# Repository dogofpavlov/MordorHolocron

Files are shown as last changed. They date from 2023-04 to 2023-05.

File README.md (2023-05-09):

# Sauron Holocron
This is a Lord of the Rings themed Holocron created by Ryan The Cyber Hobbit.

What is a Holocron?  A Holocron is a Star Wars ancient repository of knowledge and wisdom that can only be accessed by those skilled in the Force. In Star Wars, Jedi use them to record and preserve their teachings, creating a record for future generations seeking to understand the mysteries of the Force.

This is a "What if" scenario where we imagine Sauron in the Star Wars universe as a Sith Lord that created a Holocron.

This project was created with the help of this Thingiverse model, I used the "blank" option included: https://www.thingiverse.com/thing:3565057 

### 3D Printing Directions
I printed the models with a resin printer (Saturn 2) and few parts with my Creality Ender 3 Pro

### Build Video

* [Watch on my youtube channel](https://www.youtube.com/watch?v=eRCXtB5M6yg)

### Things I Used
* A Resin or FDM 3D Printer. I used a Saturn 2 (resin).
* Elegoo 405nm Standard Resin Grey 1000g
* Elegoo 405nm Standard Resin Clear Red 500g
* [Arduino Nano](https://www.amazon.com/dp/B07G99NNXL)
* [WS2812B LED Strip 60Pixels/M - 16.4 FT](https://www.amazon.com/dp/B01CDTEJBG)
* [1000mAh Lipo Rechargeable Battery with JST Connector](https://www.amazon.com/dp/B07BTV3W87)
* [SparkFun LiPo Charger/Booster - 5V/1A](https://www.amazon.com/dp/B076953CYL)
* [4 Inch Micro Male to Female USB Extension Cable](https://www.amazon.com/dp/B071NR19BQ)
* [Momentary Tactile Push Button Switch - 12mm x 12mm x 4.3mm](https://www.amazon.com/dp/B07CG6HVY9)
* [Slide Toggle Switches 3 Pin 2 Position - 12.7mm x 6.6mm x 13.2mm (l*w*h)](https://www.amazon.com/dp/B08H5BQ6Y8)
* [1000uf 25V Capacitor](https://www.amazon.com/dp/B06WGPNM19)
* [Micro SD Card 8GB Max](https://www.amazon.com/dp/B085ZVG84C)
* [1K Resistor](https://www.amazon.com/dp/B06WRQS97C)
* [330 ohm Resistor](https://www.amazon.com/dp/B06WRQS97C)
* [Mini MP3 Player - DFPlayer](https://www.amazon.com/dp/B07Y2YKYRS)
* [3 Watt 8 Ohm Speaker](https://www.amazon.com/dp/B07FTB281F)
* Use a breadboard to test everything before you Solder
* Plenty of Solder (70+ connections)
* [Krylon Flat Black Spray Paint](https://www.amazon.com/Krylon-K05546007-COLORmaxx-Spray-Aerosol/dp/B07LFWTW93) 
* [Krylon Flat Clear Coat](https://www.amazon.com/Krylon-K05547007-COLORmaxx-Spray-Aerosol/dp/B07LFWTQNG)
* [Dupli-Color Metal Cast Red](https://www.amazon.com/dp/B000994BUM)
* [Rub 'n Buff - Antique Gold](https://www.amazon.com/dp/B0BC224DPV)
* Sand Paper (320, 600, 1000) grit
* Hot Glue
* Gorilla Super Glue Gel
* [J-B Weld Plastic Bonder](https://www.amazon.com/dp/B01IBOK7FE)

### Arduino Prerequisites
* Some experience with [Arduino](https://www.arduino.cc/)
* Be sure to have the Arduino Nano board installed in your environment.
* Install the [Bounce2](https://github.com/thomasfredericks/Bounce2) library.
* Install the [ButtonEvents](https://github.com/fasteddy516/ButtonEvents) library.
* Install the [DFPlayer Mini Fast](https://github.com/PowerBroker2/DFPlayerMini_Fast) library
If you alter the number of LEDs you use, be sure to change the code "NUM_LEDS" to reflect this.

### Wiring Diagram
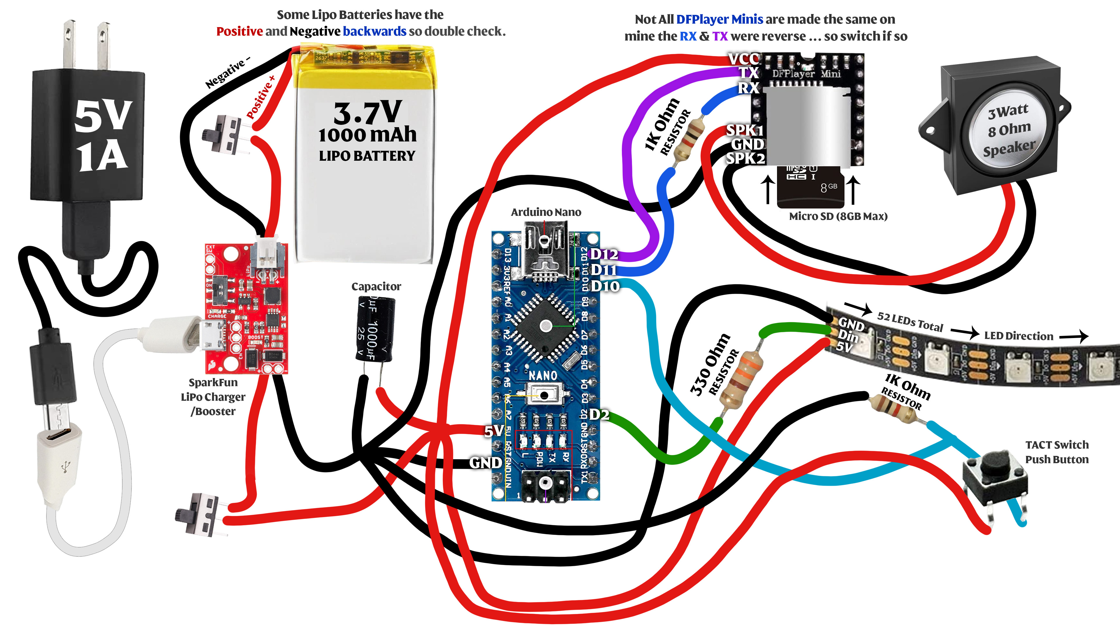
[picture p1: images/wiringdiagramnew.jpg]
Wiring diagram


### Author
Ryan "The Cyber Hobbit"

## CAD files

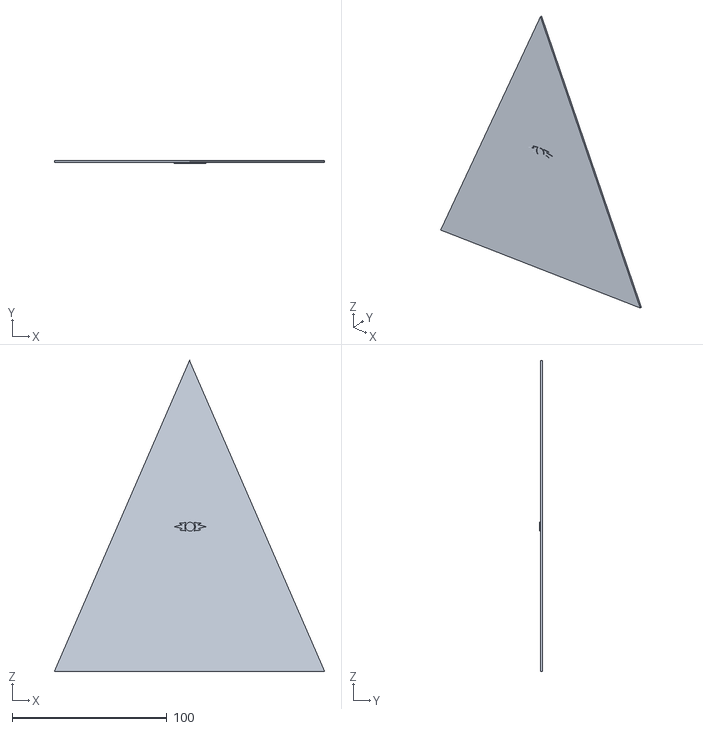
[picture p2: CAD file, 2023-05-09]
InnerPanel.stl
175.0 x 1.75 x 201.2

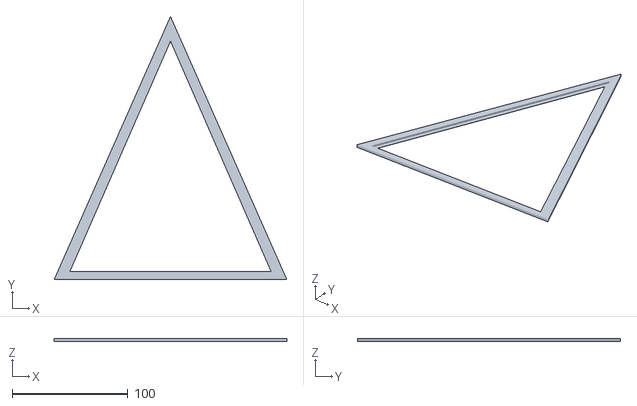
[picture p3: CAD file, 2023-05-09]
InsideFrame.stl
201.2 x 227.5 x 2.45

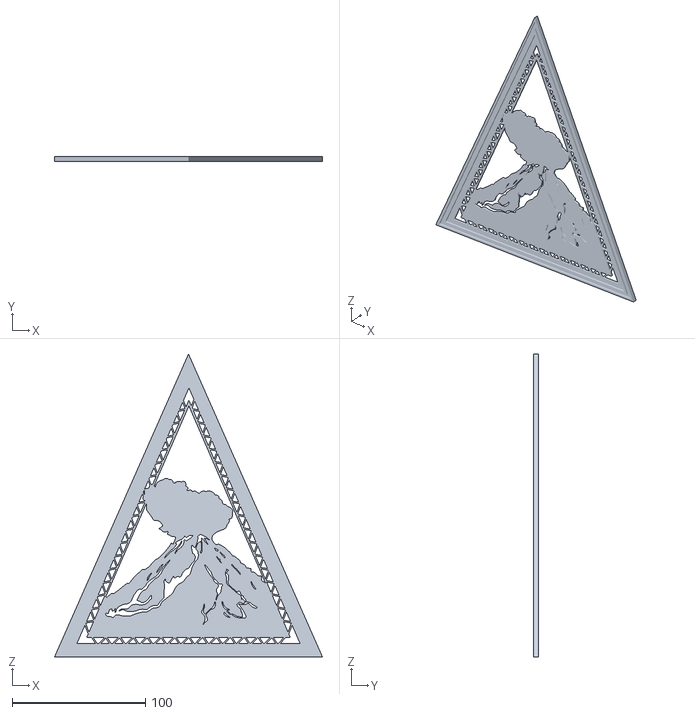
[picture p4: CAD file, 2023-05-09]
Side Mount Doom.stl
201.2 x 3.50 x 227.5

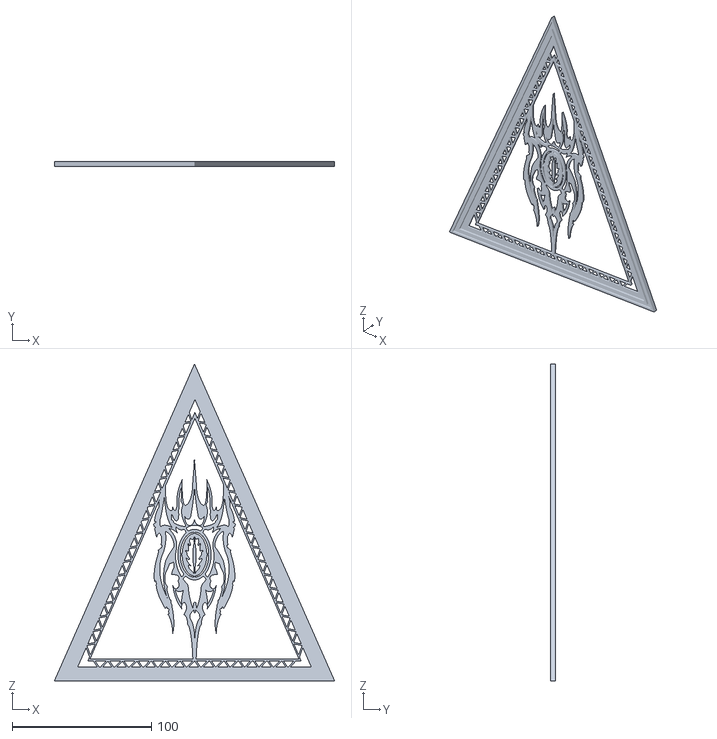
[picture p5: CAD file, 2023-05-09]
Side Eye.stl
201.2 x 3.50 x 227.5

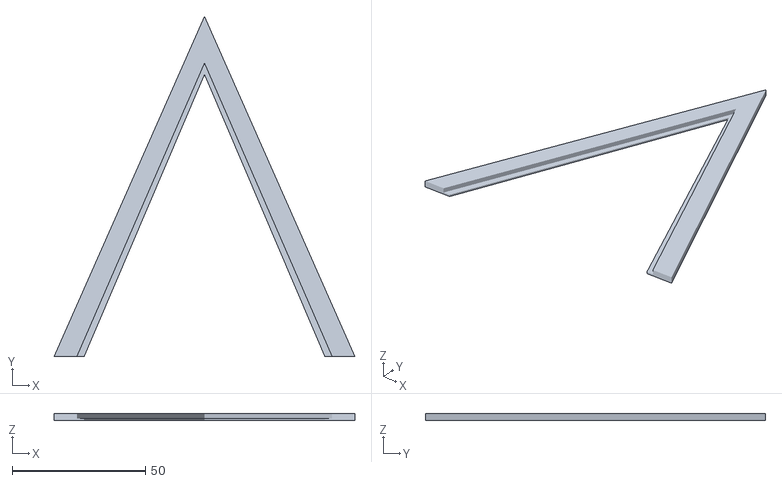
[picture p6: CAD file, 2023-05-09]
InsideFramePart1.stl
112.8 x 127.5 x 2.45

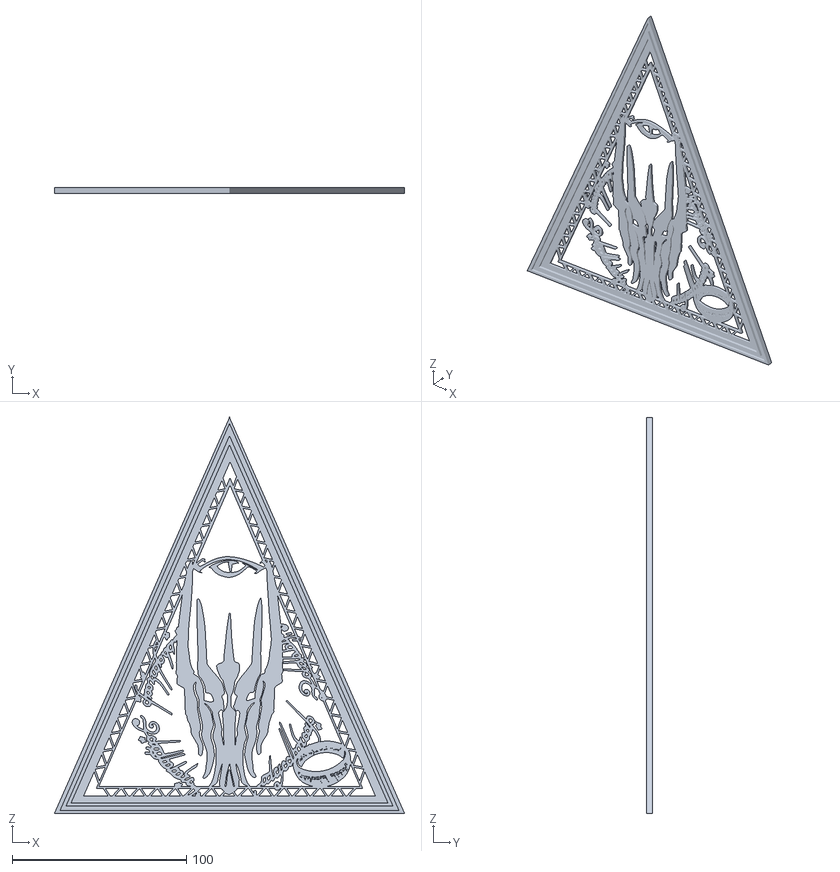
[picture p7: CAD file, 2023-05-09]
Side Sauron.stl
201.2 x 3.50 x 227.5

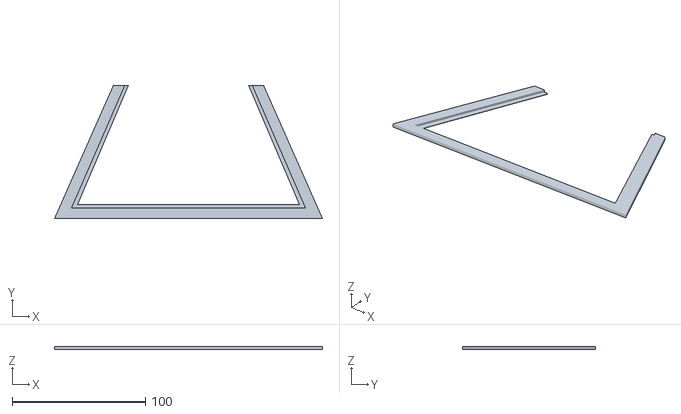
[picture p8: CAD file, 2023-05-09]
InsideFramePart2.stl
201.2 x 100.0 x 2.45

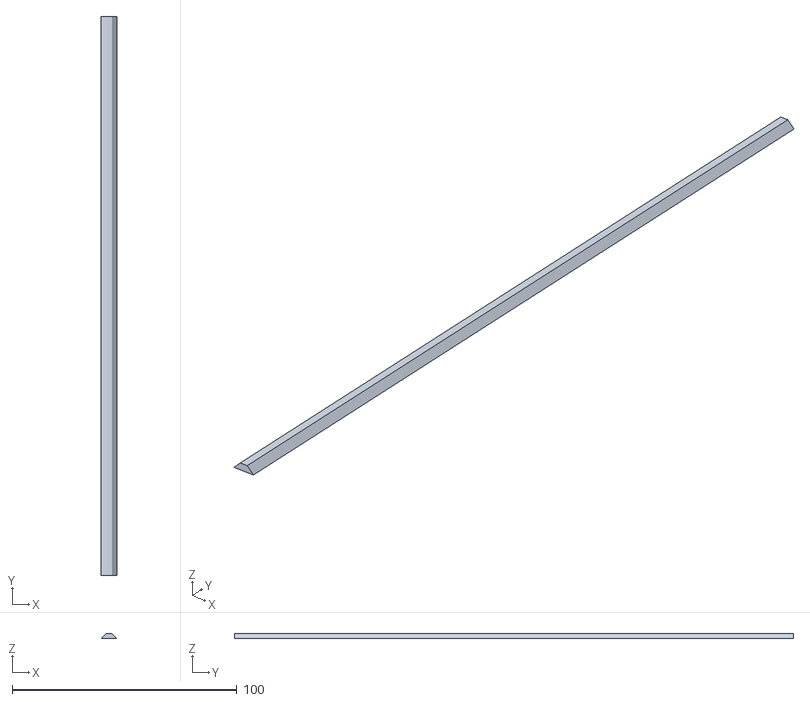
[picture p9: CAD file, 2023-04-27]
Seam.stl
7.00 x 249.0 x 2.25

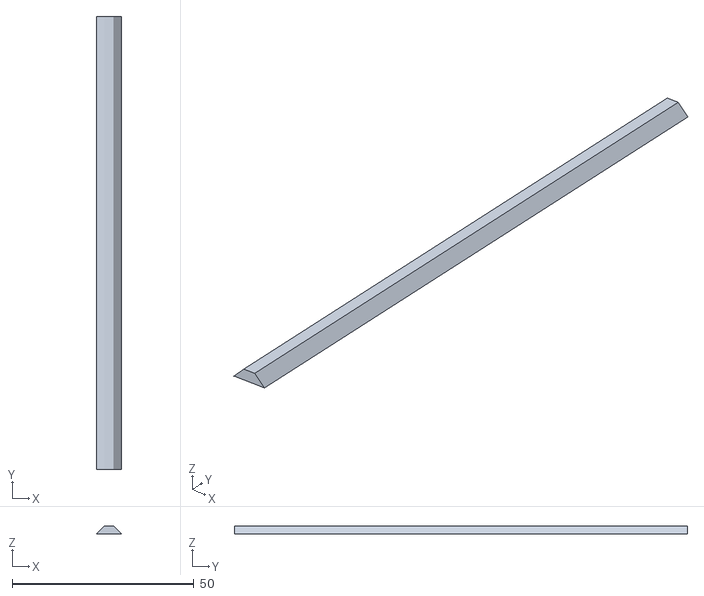
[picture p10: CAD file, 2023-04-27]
SeamPart1.stl
7.00 x 124.5 x 2.25

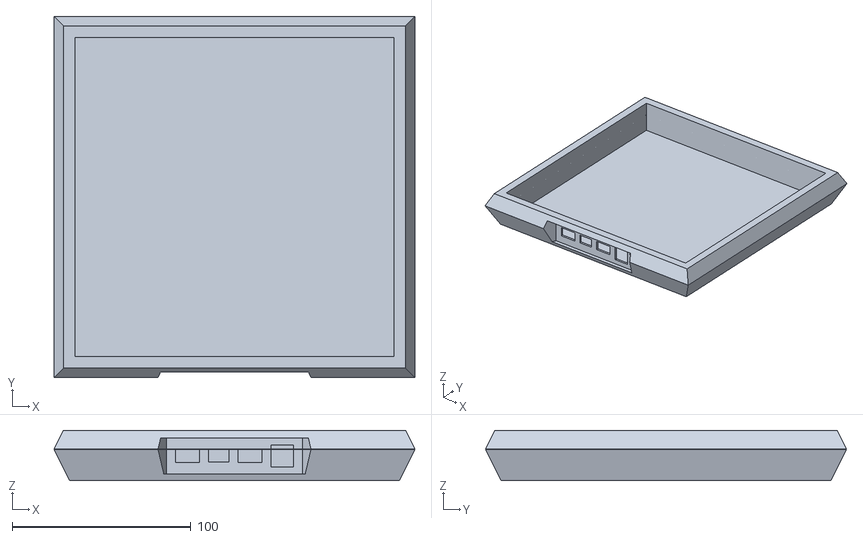
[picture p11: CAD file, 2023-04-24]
Bottom.stl
202.1 x 202.1 x 28.0

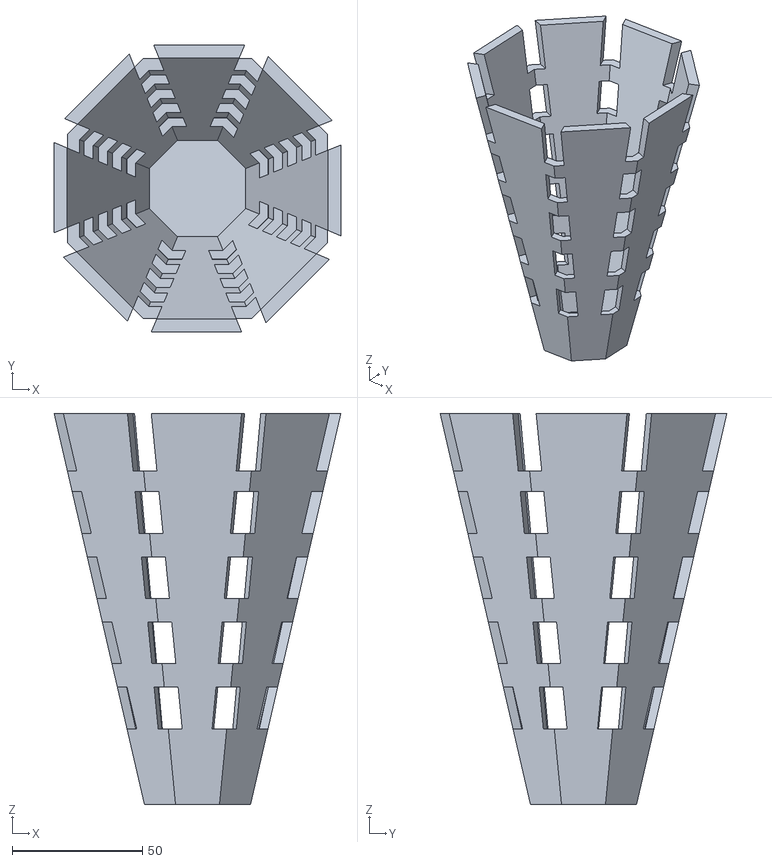
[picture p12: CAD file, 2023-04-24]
InsidePylon.stl
110.0 x 110.0 x 150.0

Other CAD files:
Side Barad Dur.stl
SeamPart2.stl

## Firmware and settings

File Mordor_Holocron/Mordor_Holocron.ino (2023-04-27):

#include <FastLED.h>

#include <Bounce2.h>
#include <ButtonEvents.h>
#include <DFPlayerMini_Fast.h>

//SOUND DECLARATIONS START
#include "SoftwareSerial.h"
const int RX_PIN = 11;
const int TX_PIN = 12;
SoftwareSerial mySerial(RX_PIN, TX_PIN);

DFPlayerMini_Fast myMP3;

//sound indexes are 1 based index not 0
const int SOUNDS_TOTAL = 13;
int CUR_SOUND = 1;//Starting on music

bool canPlaySound = true;
bool canLoopSound = false;
bool canLoopAllSound = false;

const int SOUND_MODE_SINGLE_PLAY = 0;
const int SOUND_MODE_SINGLE_STOP = 1;
const int SOUND_MODE_LOOP_PLAY = 2;
const int SOUND_MODE_LOOP_STOP = 3;
const int SOUND_MODE_CONTINUE_PLAY = 4;
const int SOUND_MODE_CONTINUE_STOP = 5;

int SOUND_MODE = SOUND_MODE_SINGLE_PLAY;

//SOUND END


#define NUM_LEDS 52
#define LED_PIN 2
#define BTN_PIN 10


CRGB leds[NUM_LEDS];

int animationModesTotal = 7;
int animationModeIndex = 0;//default fade in and out


ButtonEvents primaryButton = ButtonEvents(); 


void setup() {
  Serial.begin(115200);
  
  FastLED.addLeds<WS2812B, LED_PIN, GRB>(leds, NUM_LEDS);
  FastLED.setBrightness(60);

  initButtons();
  initSound();
}


void loop() {
  loopButtons();
  loopLEDs();
}

/**
 * HELPER FUNCTIONS
 */

int getRelativeIndex(int index){
    int relativeIndex = index;
    if(index>NUM_LEDS-1){
       relativeIndex = index-NUM_LEDS;
    }
    if(index<0){
      relativeIndex = NUM_LEDS+index;
    }
   return relativeIndex;
}


void nextSongAndAnimation(){
  nextAnimation();
  nextSound();
}
void prevSongAndAnimation(){
  prevAnimation();
  prevSound();
}

/**
 * SOUND
 */

void initSound(){
  mySerial.begin(9600);
  myMP3.begin(mySerial, true);
  delay(2000);
  myMP3.volume(30);
  delay(1000);
  myMP3.play(CUR_SOUND);
}

void playCurrentSound(){
  canPlaySound=true;
  myMP3.play(CUR_SOUND);  
}
void playLoopSound(){
  canLoopSound=true;
  myMP3.loop(CUR_SOUND);
}
void playLoopAllSound(){
  canLoopAllSound=true;
  myMP3.startRepeatPlay();
}

void stopSound(){

  if(canLoopAllSound){
    canLoopAllSound=false;
    myMP3.stopRepeatPlay();
  }else{
    canPlaySound=false;
    canLoopSound=false;
    myMP3.stop();
  }
}

void nextSoundIndex(){
  CUR_SOUND++;
  if(CUR_SOUND==SOUNDS_TOTAL+1){
    CUR_SOUND=1;
  }  
}
void prevSoundIndex(){
  CUR_SOUND--;
  if(CUR_SOUND==0){
    CUR_SOUND=SOUNDS_TOTAL;
  }
}

void nextSound(){
  if(canPlaySound){
    nextSoundIndex();
    playCurrentSound();
  }
  if(canLoopSound){
    nextSoundIndex();
    playLoopSound();
  }
  if(canLoopAllSound){
    myMP3.playNext();
  }
}
void prevSound(){
  if(canPlaySound){
    prevSoundIndex();
    playCurrentSound();
  }
  if(canLoopSound){
    prevSoundIndex();   
    playLoopSound(); 
  }
  if(canLoopAllSound){
    myMP3.playPrevious();
  }
}





/**
 * BUTTONS
 */

void initButtons(){

  primaryButton.attach(BTN_PIN, INPUT);  
  primaryButton.activeHigh();
  primaryButton.debounceTime(15);
  primaryButton.doubleTapTime(500);
  primaryButton.holdTime(2000);
  
}

void nextSoundMode(){
  switch(SOUND_MODE){
    case SOUND_MODE_SINGLE_PLAY:
      soundModeSingleStop();
    break;
    case SOUND_MODE_SINGLE_STOP:
      soundModeLoopPlay();
    break;
    case SOUND_MODE_LOOP_PLAY:
      soundModeLoopStop();
    break;
    case SOUND_MODE_LOOP_STOP:  
      soundModeContinuePlay(); 
    break;
    case SOUND_MODE_CONTINUE_PLAY:
      soundModeContinueStop();
    break;
    case SOUND_MODE_CONTINUE_STOP: 
      soundModeSinglePlay(); 
    break;
  }
}

void soundModeSinglePlay(){    
  SOUND_MODE = SOUND_MODE_SINGLE_PLAY;
  playCurrentSound();  
}
void soundModeSingleStop(){
  SOUND_MODE = SOUND_MODE_SINGLE_STOP;
  stopSound();
}
void soundModeLoopPlay(){
  SOUND_MODE = SOUND_MODE_LOOP_PLAY;
  playLoopSound();
}
void soundModeLoopStop(){
  SOUND_MODE = SOUND_MODE_LOOP_STOP;
  stopSound();
}
void soundModeContinuePlay(){
  SOUND_MODE = SOUND_MODE_CONTINUE_PLAY;
  playLoopAllSound();   
}
void soundModeContinueStop(){
  SOUND_MODE = SOUND_MODE_CONTINUE_STOP;
  stopSound();  
}


void loopButtons(){
  bool changed = primaryButton.update();

  // Was the button pushed?
  if (changed){
    int event = primaryButton.event(); // Get how the button was pushed

    switch(event){
      case(tap):
        Serial.println(F("Primary button single press..."));
        nextSongAndAnimation();  
        break;
      case (doubleTap):
        Serial.println(F("Primary button double press..."));
        prevSongAndAnimation();
        break;
      case (hold):
        Serial.println(F("Primary button long press..."));
        nextSoundMode();        
        break;
    }
  }
}


/*
 * LEDS
 */

void nextAnimation(){
  animationModeIndex++;
  if(animationModeIndex==animationModesTotal){
    animationModeIndex=0;
  }  
}
void prevAnimation(){
  animationModeIndex--;
  if(animationModeIndex<0){
    animationModeIndex=animationModesTotal-1;
  }  
}
 
void loopLEDs(){

  switch(animationModeIndex){
    case 0:
      modeFadeChaos();
    break;
    case 1:
      modeRain();
    break;
    case 2:
      resetLEDs();
      modeWaveForward();
    break;
    case 3:
      resetLEDs();
      modeWaveBackward();
    break;
    case 4:
      resetLEDs();
      modeWaveChaos();
    break;
    case 5:
      modeColorRed();
    break;
    case 6:
      modeColorBlue();
    break;
  }
  
  FastLED.show();
  
}

void resetLEDs(){
 //brightness reset
  for(int i = 0; i< NUM_LEDS; i++){
    leds[i] = CHSV(0,255,0);
  }
}

/**
 * FADE ANIMATION
 */

int fadeIndex = 0;
int fadeSteps = 50;
int fadePerStep = ((int)255/fadeSteps);
int fadeDir = 1;


int fadeStepsToChangeCur = 0;
int fadeStepsToChangeOnTotal = 200;
int fadeStepsToChangeOffTotal = 30;
int fadeColor = 0;
int fadeMinimum = 0;

 
void modeFadeChaos(){
  EVERY_N_MILLISECONDS(15){

    int brightness = fadePerStep*fadeIndex;
    if(brightness>255){
      brightness = 255;
    }
    if(brightness<fadeMinimum){
      brightness = fadeMinimum;
    }
    
    for(int i = 0; i< NUM_LEDS; i++){
      leds[i] = CHSV(fadeColor,255,brightness);
    }
    fadeIndex=fadeIndex+fadeDir;
    
    if(fadeIndex>=fadeSteps-1){

      fadeStepsToChangeCur++;
      if(fadeStepsToChangeCur==fadeStepsToChangeOnTotal){
        fadeStepsToChangeCur=0;
        fadeDir = -1;
        fadeIndex = fadeSteps-1;
        
      }
      
    }
    if(fadeIndex<=-1){
      fadeStepsToChangeCur++;
      if(fadeStepsToChangeCur==fadeStepsToChangeOffTotal){
        fadeStepsToChangeCur=0;
        fadeDir = 1;
        fadeIndex = 0;
        
        fadeStepsToChangeOnTotal = ((int)random(100,300));

        if(fadeMinimum==0){
          fadeColor = ((int)random(0,15));
          

          int randomForceRed = ((int)random(0,5));
          if(randomForceRed>3){
            fadeColor = 0;
          }
        }


      }
      
    }
  } 
}


/**
 * SOLID COLOR RED
 */

 int modeColorValue = 0;
 int modeColorSat = 255;
 int modeColorBrightness = 255;

 void modeColorRed(){
  modeColorValue = 0;
  modeColorSat = 255;
  modeColorBrightness = 255;
  modeColor();
 }
 void modeColorBlue(){
  modeColorValue = 160;
  modeColorSat = 255;
  modeColorBrightness = 255;
  modeColor();
 }
 void modeColor(){
    for(int i = 0; i< NUM_LEDS; i++){
        leds[i] = CHSV(modeColorValue,modeColorSat,255);        
    }
 }

/**
 * RAIN ANIMATION
 */


void modeRain(){

  EVERY_N_MILLISECONDS(30){
    for(int i = 0; i< NUM_LEDS; i++){

      int rainColor = ((int)random(0,20));
      
      int brightness = ((int)random(0,255));

      int canChange = ((int)random(0,10));

      if(canChange>8){
        leds[i] = CHSV(rainColor,255,brightness);

        
      }
      
    }

  }

}


/**
 * WAVE ANIMATION
 */


int curWaveIndex = 0;
uint8_t waveSideBuffer = 15;
uint8_t waveSize = 15;

int waveColorFrom = 0;
int waveColorTo = 20; //orange
int waveColorIndex = 0;
int waveColorSteps = 20;
int waveColorDir = 1;

int waveColorRange = waveColorTo-waveColorFrom;
int waveColorStep =  ((int)waveColorRange/waveColorSteps);

int waveSpeed = 30;

void modeWaveForward(){
  wave();
  EVERY_N_MILLISECONDS(waveSpeed){
    waveMoveForward(); 
  }
}
void modeWaveBackward(){
  wave();
  EVERY_N_MILLISECONDS(waveSpeed){
    waveMoveBackward();
  } 
}
void modeWaveChaos(){
  wave();
  EVERY_N_MILLISECONDS(waveSpeed){
    waveMoveChaos();
  } 
}

void wave(){
  int waveLoopColor = waveColorFrom+(waveColorStep*waveColorIndex);
  
  //wave
  for(int i=0; i<waveSize; i++){
    int index = getRelativeIndex(curWaveIndex+i);
    leds[index] = CHSV(waveLoopColor,255,255);    
  }
  
  int bufferStep = ((int)255/waveSideBuffer);
  
  //wave buffer
  for(int i=0; i<waveSideBuffer; i++){ 
    int brightness = 255-(bufferStep*i);
    
    //front
    int indexF = getRelativeIndex(curWaveIndex+waveSize+i);   
    leds[indexF] = CHSV(waveLoopColor,255,brightness);    

    //back
    int indexB = getRelativeIndex(curWaveIndex-(i+1));
    leds[indexB] = CHSV(waveLoopColor,255,brightness);
  }

  EVERY_N_MILLISECONDS(300){ 
    waveColorIndex = waveColorIndex+waveColorDir;
    if(waveColorIndex==waveColorSteps){
      waveColorDir = -1;
      waveColorIndex = waveColorSteps+waveColorDir;
    }
    if(waveColorIndex==-1){
      waveColorDir = 1;
      waveColorIndex = 1;
    }
  }
}



int chaosStepIndex = 0;
int chaosStepsToChange = 10;
int chaosDir = 1;

void waveMoveChaos(){

  chaosStepIndex++;
  if(chaosStepIndex == chaosStepsToChange){
    chaosStepIndex = 0;
    chaosStepsToChange = ((int)random(5,100));
    if(chaosDir==1){
      chaosDir=-1;
    }else{
      chaosDir=1;
    }    
  }
  curWaveIndex = curWaveIndex+chaosDir;  
  wrapWaveIndex();
}

void waveMoveForward(){
    curWaveIndex++;
    wrapWaveIndex();
}
void waveMoveBackward(){
    curWaveIndex--;
    wrapWaveIndex();  
}

void wrapWaveIndex(){
    if(curWaveIndex>NUM_LEDS-1){
      curWaveIndex = 0;
    }
    if(curWaveIndex==-1){
      curWaveIndex = NUM_LEDS-1;
    }
}

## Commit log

2023-04-18 Working Code / Models / Audio
    [InsideFrameSmall1.stl, InsideFrameSmall2.stl, InsideFrameSmaller.stl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]
2023-04-18 wiring diagram
2023-04-24 Changing some defaults and adding a new sound Including the inside Pylon and Bottom that is already scaled to 175%
    [175Bottom.stl, InsidePylon.stl]
2023-04-27 Last minute code changes and some models for Seams in case of light gaps between panels.
    [Seam.stl, Seam1.stl, Seam2.stl]
2023-04-27 update wirediagram
2023-04-27 Wiring Diagram won't update? wtf github
2023-04-27 fine github, I'll make a new image to update the wiring diagram because you are showing a cached version????
2023-05-09 Final Update, all models at the right size
    [Bottom.stl, InsideFrame.stl, InsideFramePart1.stl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]
2023-05-09 Inner Panel
    [InnerPanel.stl]
